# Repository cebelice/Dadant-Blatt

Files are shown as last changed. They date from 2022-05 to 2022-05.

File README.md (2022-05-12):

Dadant-Blatt panj
=================
Projekt vključuje detajlne risbe za izdelavo čebeljega nakladnega panja tipa Dadant-Blat.

Panj vključuje visoko podnico s smukalnikom cvetnega prahu oz. testno ploščo za varojo. Zasnova in dimenzije so plod raziskav slovenskih čebelarjev.

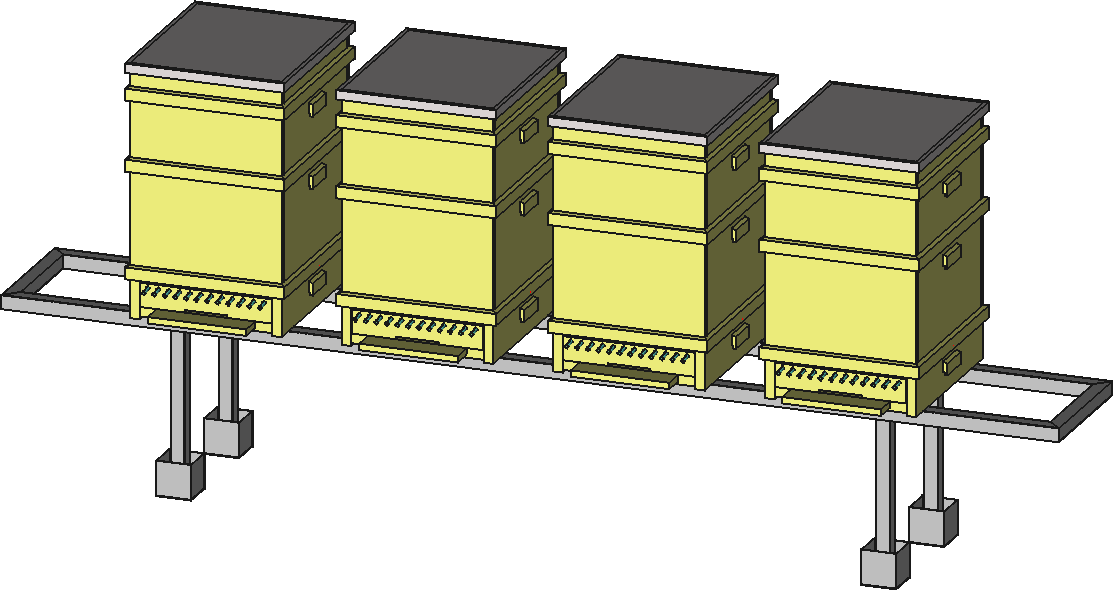
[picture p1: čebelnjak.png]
Čebelnjak z Dadant-Blat panji


Vsebina projekta
----------------
Projekt vsebuje 3-D model in sestavne ter delavniške risbe potrebne za izdelavo panja. Panj je možno izdelati s hobi orodjem.

Material je po večini lepljen smrekov ali jelov les, ki se dobi v obliki skobljanih plošlč različnih širin in debelin. V projektu se večinoma uporabljajo plošče debeline 18 in 27 mm, kot na [tej povezavi](https://trgovina.slovenijales.si/lesni-materiali/lepljene-plosce/lepljene-plosce-smreka/lepljena-plosca-smrekajelka-27-mm-300-x-2500-mm-kvaliteta).

3-D modeli sestavnih delov panja in samega panja imajo končnico ``.FCStd`` in se odpirajo s programom FreeCAD, ki je prost za uporabo. V posameznem modelu je npr. možno enostavno spremeniti v spremenljivkah debelino stene okvirja (npr. s 27 na 25 mm) in vse risbe letvic se avtomatsko ustrezno popravijo. Kratka navodila za uporabo v programu FreeCAD so [tukaj](FreeCAD/README.md).

Vsebina projekta so tudi ``.pdf`` datoteke z risbami, ki se lahko natisnejo. Generirane so iz posamezih ``.FCStd`` datotek. Zraven je tudi nekaj slik ``.png`` in pa datoteka LICENSE, ki [omogoča prosto uporabo](https://sl.wikipedia.org/wiki/Licenca_Apache).

Uporaba projekta in sodelovanje
-------------------------------
Projekt je prosto dostopen na https://github.com/cebelice/Dadant-Blatt. Cel projekt se lahko prenese na svoj računalnik (gumb Code).

Komentarji, težave in predlogi ali razprava lahko poteka v zavihku "Issues" (potrebna je brezplačna registracija).

Bolj vešči uporabniki lahko naredijo "Fork" projekta na svoj račun na Githubu, ga dopolnjujejo po svoje in dopolnitve po želji pošljejo nazaj kot "Pull request". "git" je orodje za nadzor različic, ki hrani celo zgodovino projekta in običajno prikazuje samo datoteke iz najnovejše verzije. Precej ga uporabljajo programerji ampak primeren je tudi za projekt, kot je tale.

Visoka podnica in smukalnik cvetnega prahu
------------------------------------------
Avtor visoke podnice in smukalnika je Brane Borštnik in daje načrte v prosto uporabo.

Viskoka podnica se lahko uporablja na dva načina:

### S smukalnikom cvetnega prahu
V podnico se od zadaj vstavi "smukalnik" in "smukalnik_mreza". Z mreže se dnevno odstranjuje cvetni prah in se ga takoj zamrzne.

### Z mrežo in testno ploščo
Namesto smukalnika se vstavi "podnica_mreza" in pod njo "testna_plosca" za varojo, ki se jo na tanko namaže z litijevo mastjo. Priporoča se izdelavo testne plošče iz materiala [Forex](http://www.sign-supply.si/forex-plosce-unipan/forex-plosce.html), 3mm.

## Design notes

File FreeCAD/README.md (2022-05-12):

Uporaba programa FreeCAD
========================

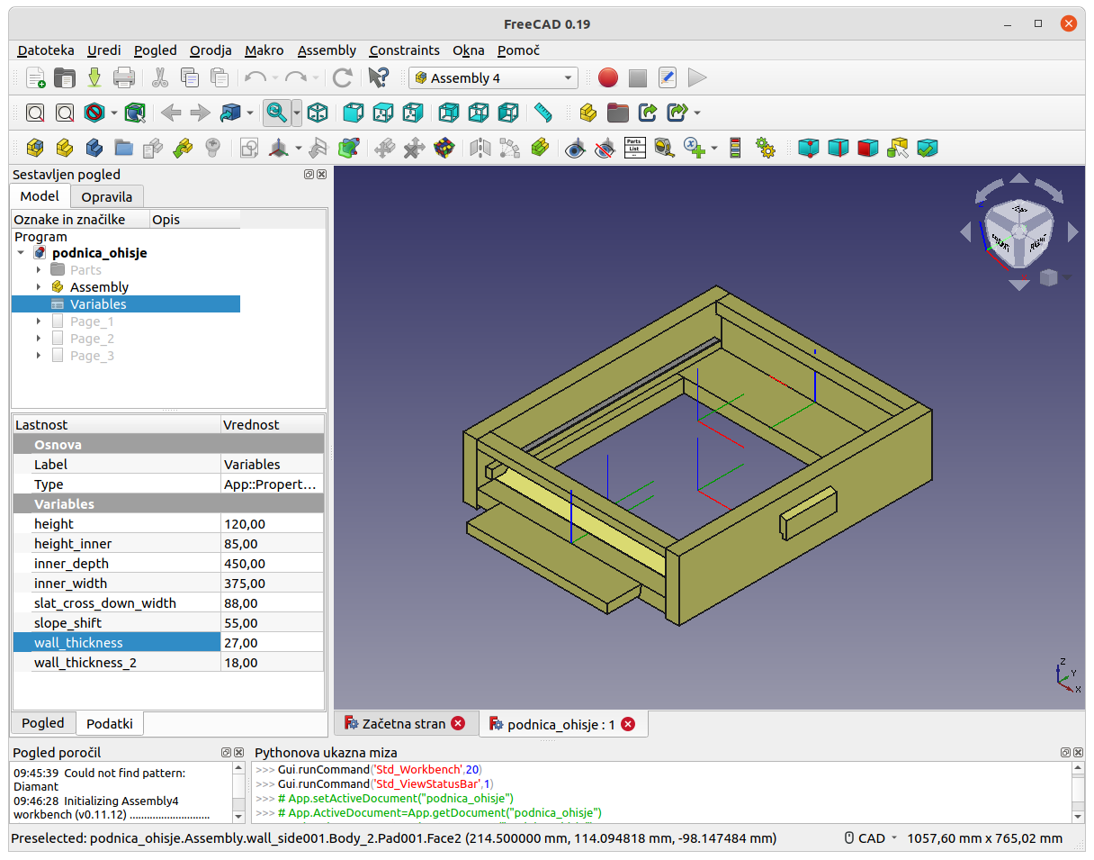
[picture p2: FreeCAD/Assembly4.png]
Assembly4

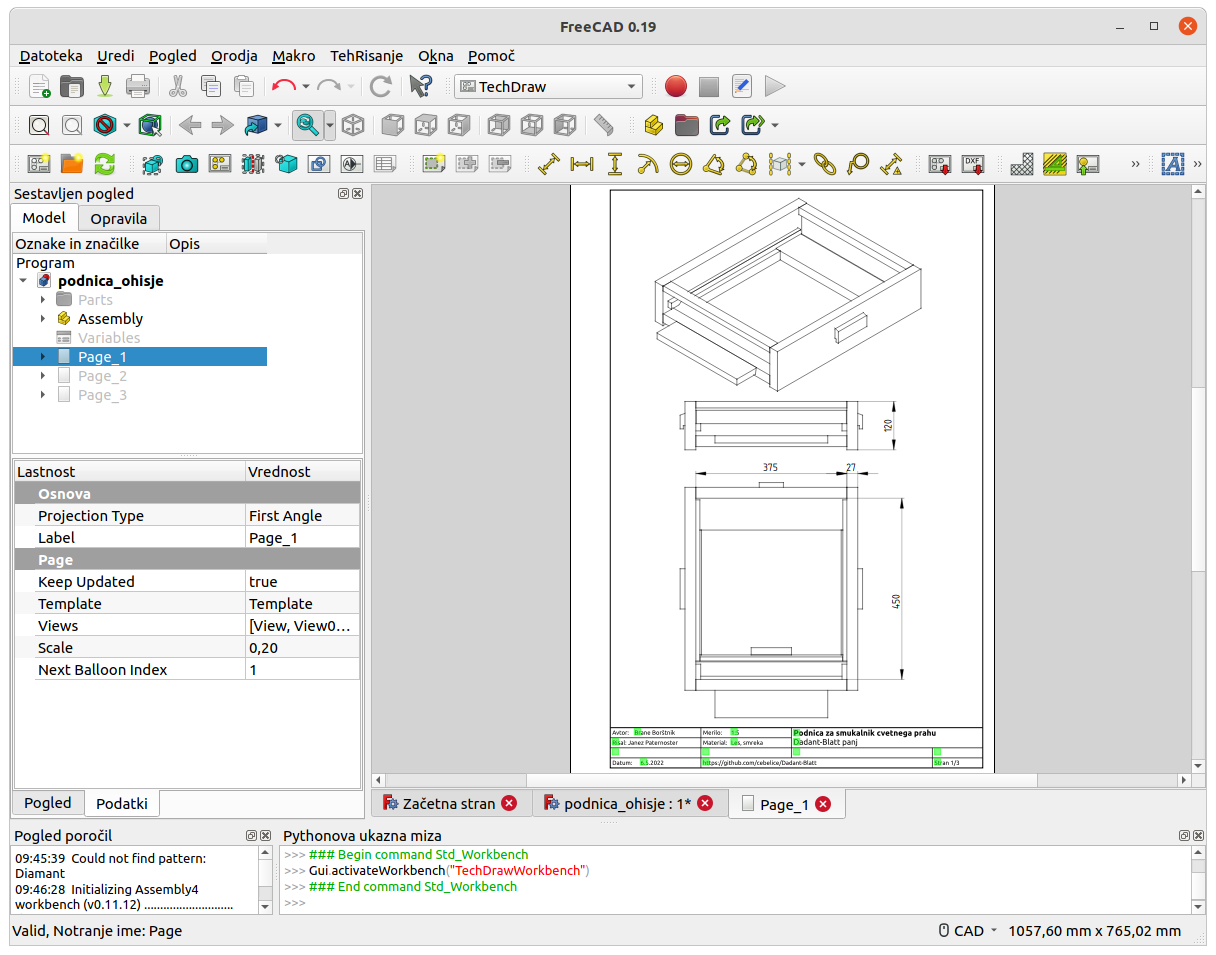
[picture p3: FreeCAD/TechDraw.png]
TechDraw


FreeCAD je prost program za tehnično 3-D modeliranje. Ni tako izpopolnjen kot podobni komercialni programi je dovolj dober za ta projekt.

Namestitev
----------
1. Namesti https://www.freecad.org/ V času tega pisanja je bila nameščena zadnja verzija, to je 0.19.
2. po nameščenem FreeCADu, znotraj programa: meni "Orodja" -> "Upravljalnik dodatkov" -> namesti modul "Assembly4"

Primeri uporabe programa
------------------------
- V programu odpreš datoteko "podnica_ohisje.FCStd".
- Desno v oknu je viden 3-D model ali 2-D risba. Premika se s pritiskom na srednjo tipko miške in vlečenjem. Vrti se s pritiskom desne tipke miške in hkratinim držanje tipke "shift" na tipkovnici.
- Okno levo zgoraj vsebuje drevesno strukturo elementov v datoteki "podnica_ohisje.FCStd":
  - Mapa "Parts" vsebuje posamezne sestavne dele modela "podnica_ohisje.FCStd".
  - Mapa "Assembly" vsebuje zgradbo celotnega sestava. Z izbiro posameznega dela v tej mapi ga lahko s tipko "preslednica" preklopimo njegovo vidnost. Isto velja za sestavne dele v mapi "Parts".
  - Predmet "Variables" vsebuje spremenljivke za dimenzije, ki se uporabljajo pri tem modelu.
    - Ob kliku na "Variables" se v spodnjem oknu pojavi seznam spremenljivk.
    - Za primer spremeni vrednost "wall_thickness" s 27 na 25 in debeline lesenih plošč v modelu se spremenijo.
    - Sprememba se odraža tudi v kotah na risbah.
  - "Page_1", "Page_2", "Page_3" (dvojni klik) vsebujejo tehnične risbe.

Model je seveda možno tudi popolnoma spremeniti. Za več informacij o uporabi programa FreeCAD glej:
- https://wiki.freecad.org/Getting_started
- https://wiki.freecad.org/Assembly4_Workbench
  - [Tutorial 1 for a quick assembly from scratch](https://github.com/Zolko-123/FreeCAD_Examples/blob/master/Asm4_Tutorial1/README.md)
  - [Tutorial 2 for a cinematic assembly in one file, using a master sketch](https://github.com/Zolko-123/FreeCAD_Examples/blob/master/Asm4_Tutorial2/README.md)
- https://wiki.freecad.org/TechDraw_Workbench
  - https://wiki.freecad.org/Basic_TechDraw_Tutorial

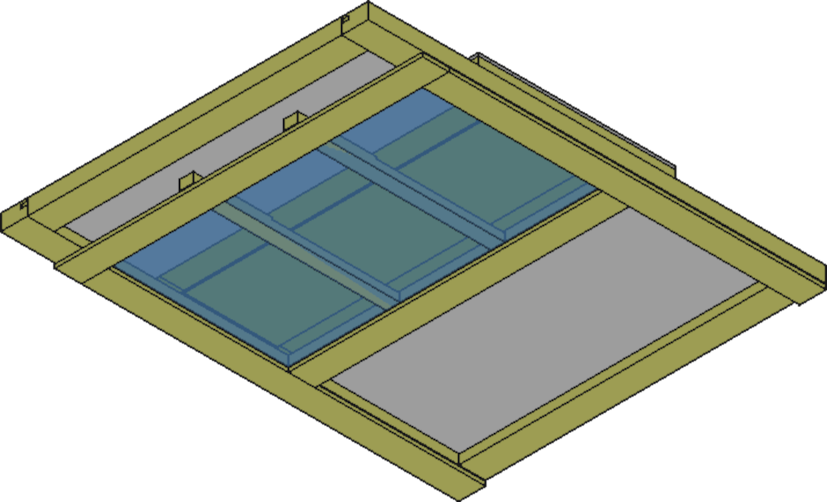
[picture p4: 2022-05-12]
smukalnik_2.png

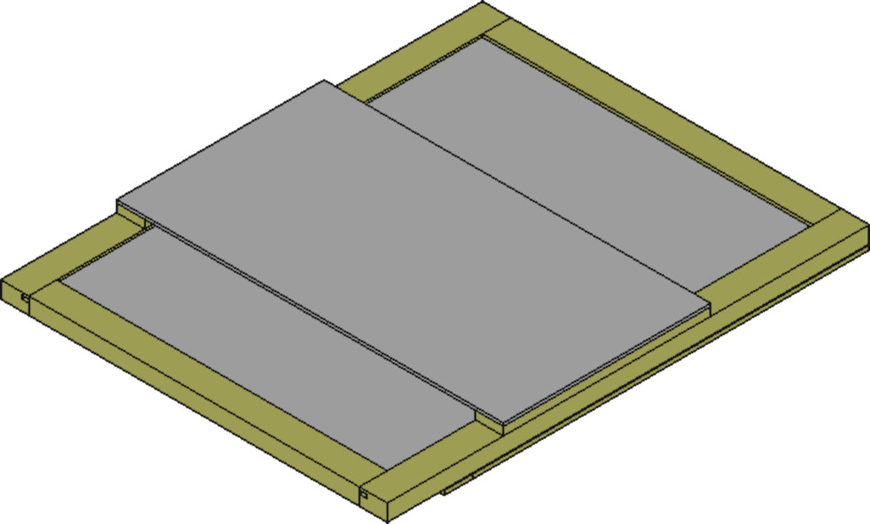
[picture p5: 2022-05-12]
smukalnik_1.png

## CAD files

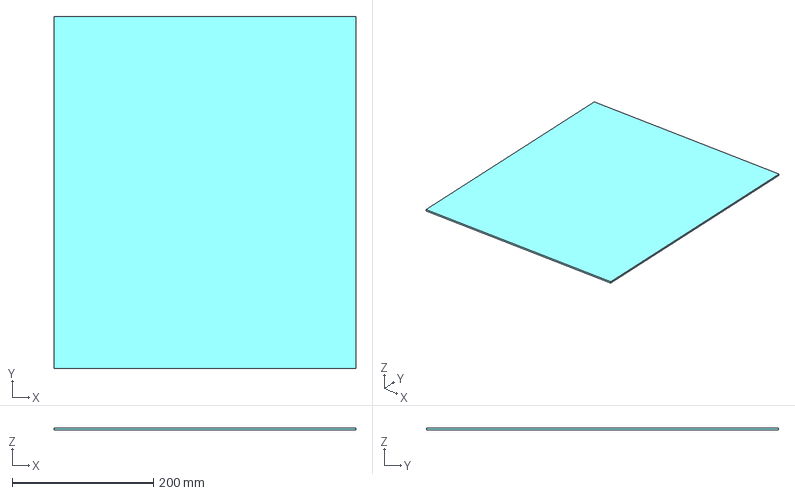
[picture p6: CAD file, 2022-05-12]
panj.FCStd
428.0 x 499.0 x 3.00 mm

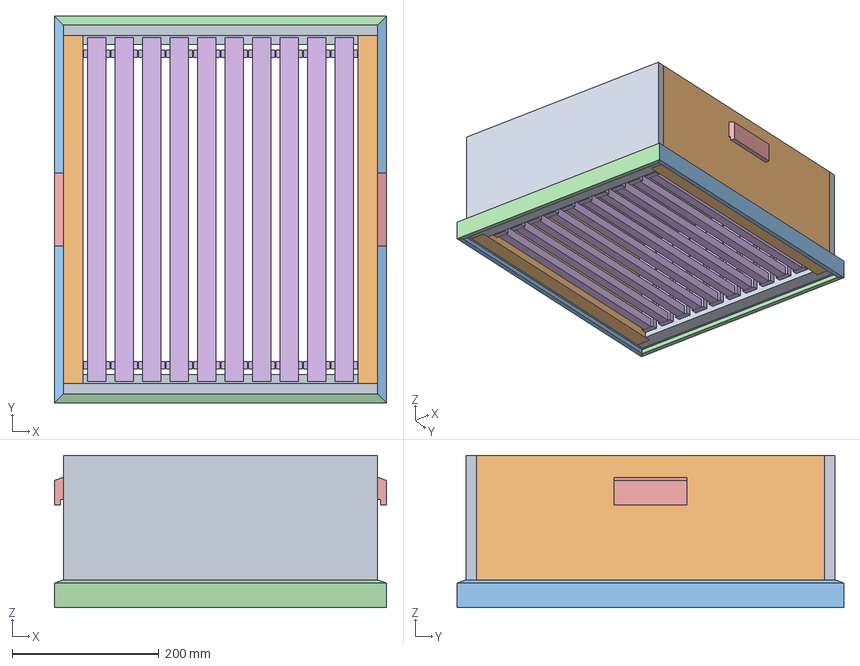
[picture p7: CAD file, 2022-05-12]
naklada_nizka.FCStd
453.0 x 528.0 x 208.0 mm

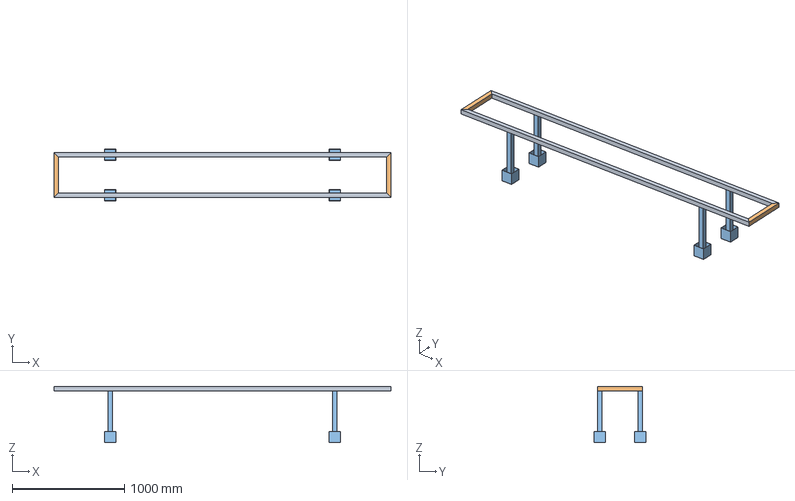
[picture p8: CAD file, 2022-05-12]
podstavek.FCStd
3000.0 x 460.0 x 500.0 mm

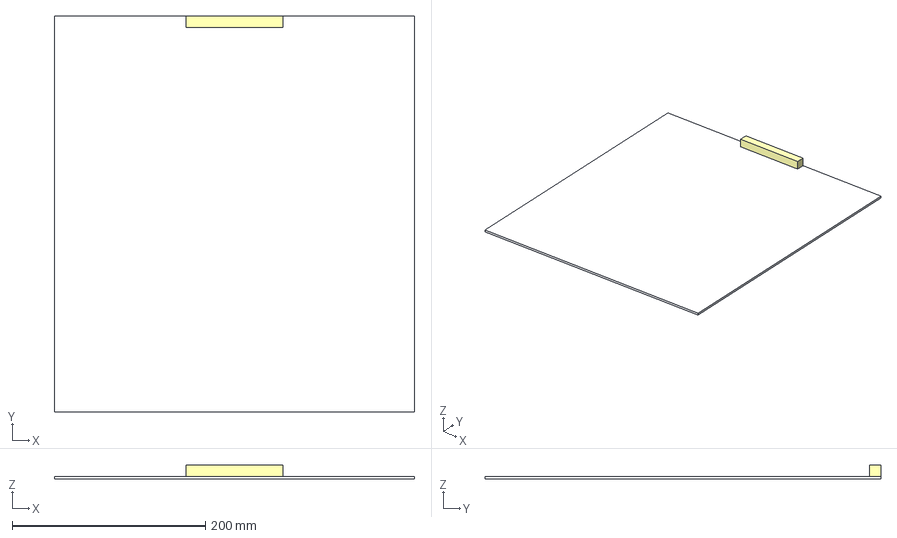
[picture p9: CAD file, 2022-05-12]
testna_plosca.FCStd
373.0 x 410.0 x 15.0 mm

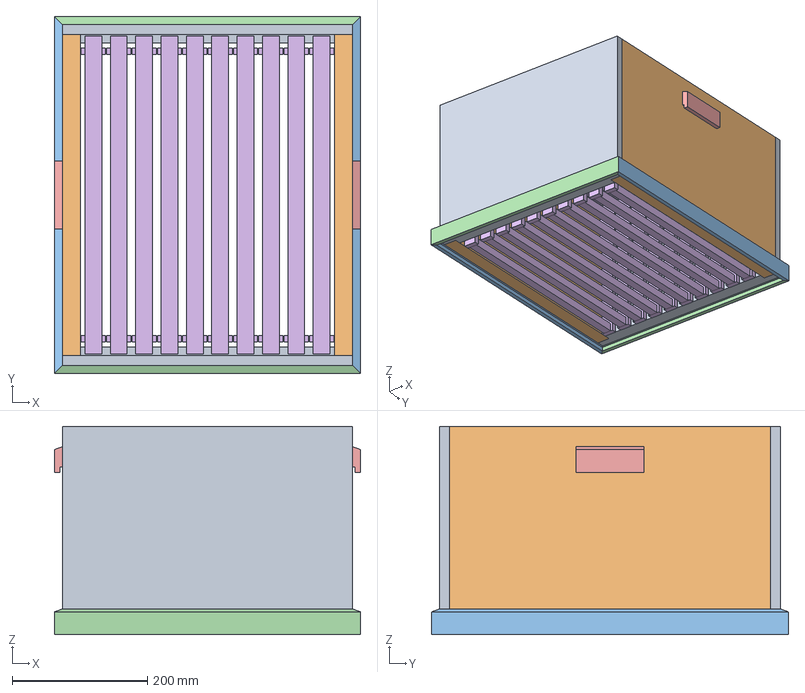
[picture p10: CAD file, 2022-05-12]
naklada.FCStd
453.0 x 528.0 x 308.0 mm

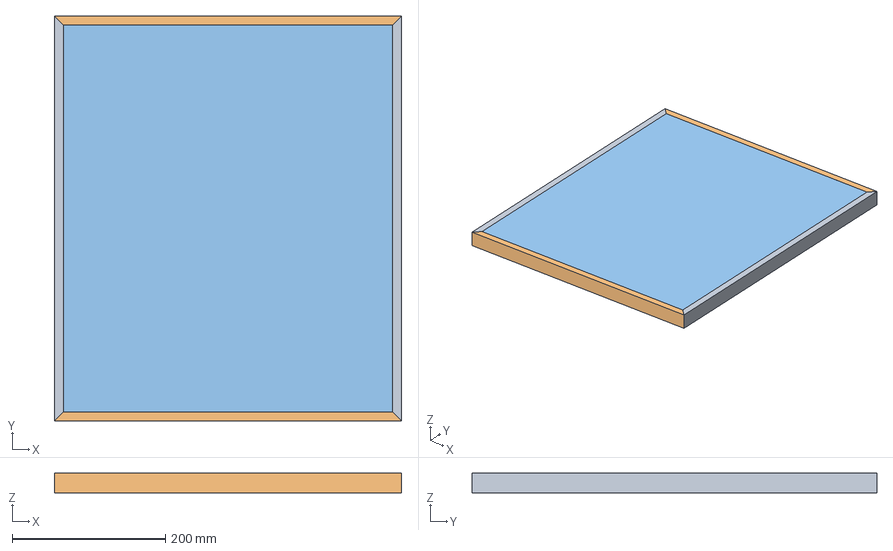
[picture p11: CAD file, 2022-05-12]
streha.FCStd
453.0 x 528.0 x 26.0 mm

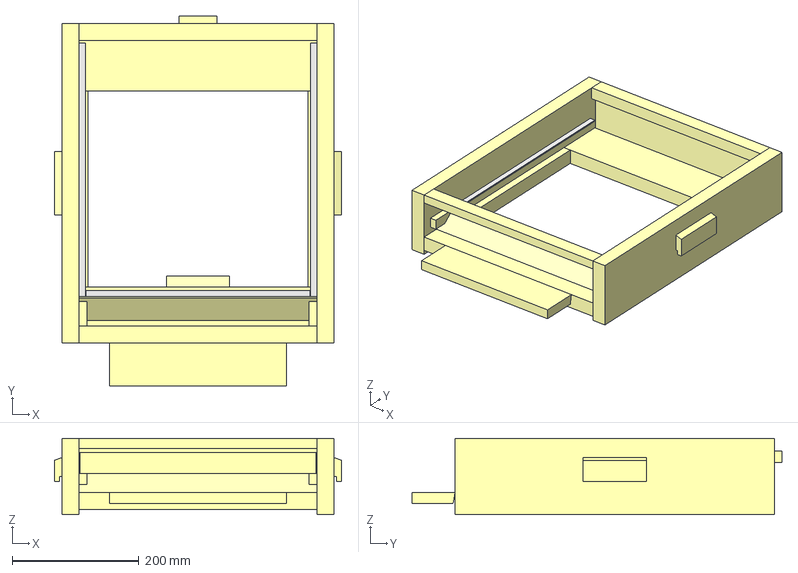
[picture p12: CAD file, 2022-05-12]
podnica_ohisje.FCStd
453.0 x 584.0 x 120.0 mm

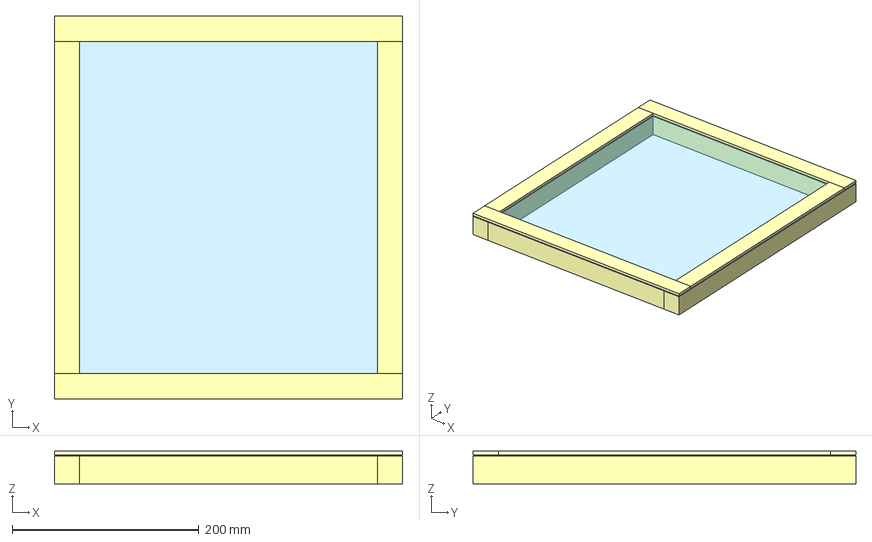
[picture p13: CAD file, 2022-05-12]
podnica_mreza.FCStd
373.0 x 410.0 x 35.0 mm

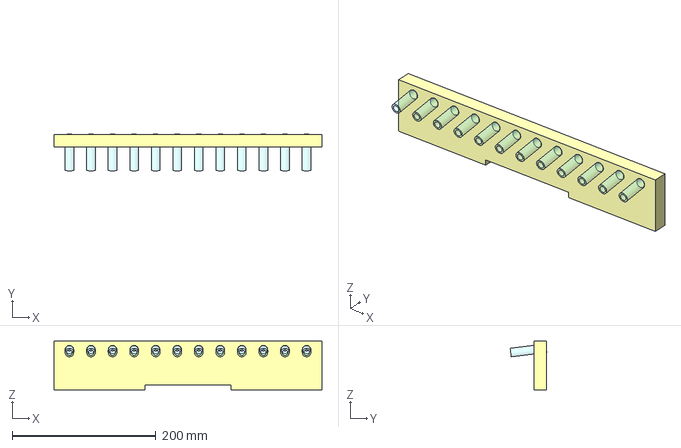
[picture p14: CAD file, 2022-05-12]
podnica_pokrovcek.FCStd
373.0 x 51.1 x 68.0 mm

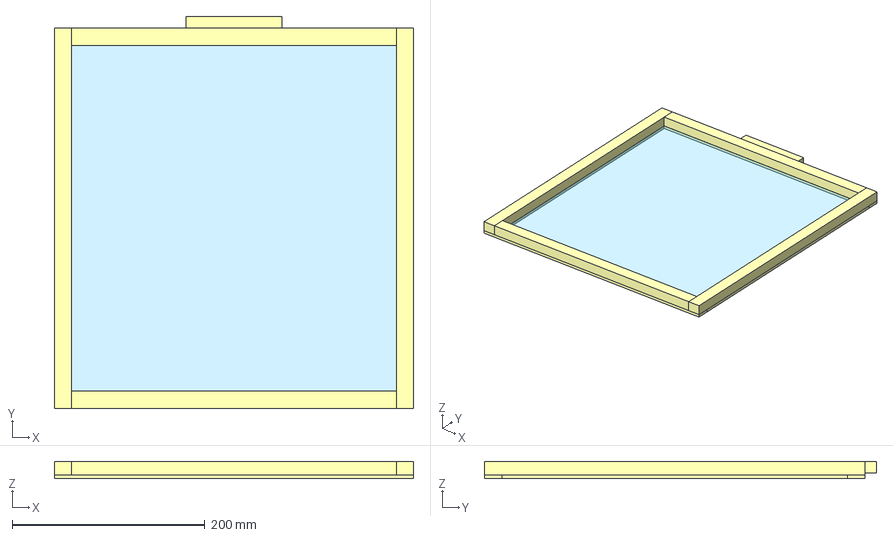
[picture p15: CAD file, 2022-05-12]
smukalnik_mreza.FCStd
373.0 x 407.0 x 18.0 mm

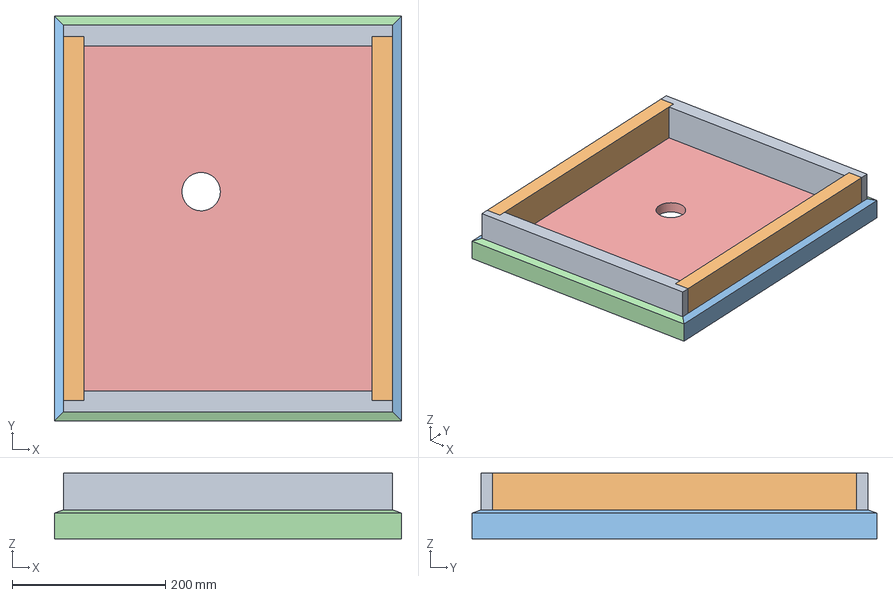
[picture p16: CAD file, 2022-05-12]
pokrov.FCStd
453.0 x 528.0 x 86.0 mm

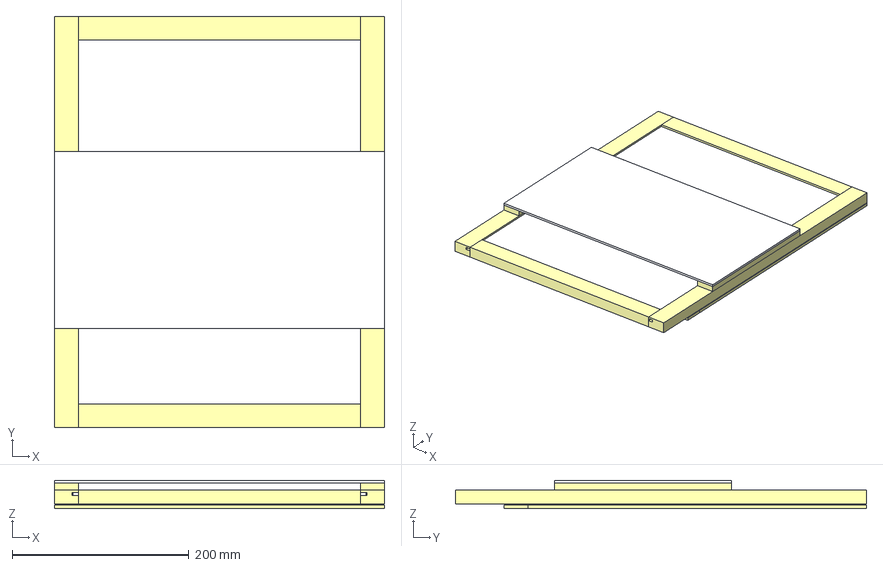
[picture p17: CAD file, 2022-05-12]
smukalnik.FCStd
373.0 x 465.0 x 32.0 mm

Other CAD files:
cebelnjak.FCStd

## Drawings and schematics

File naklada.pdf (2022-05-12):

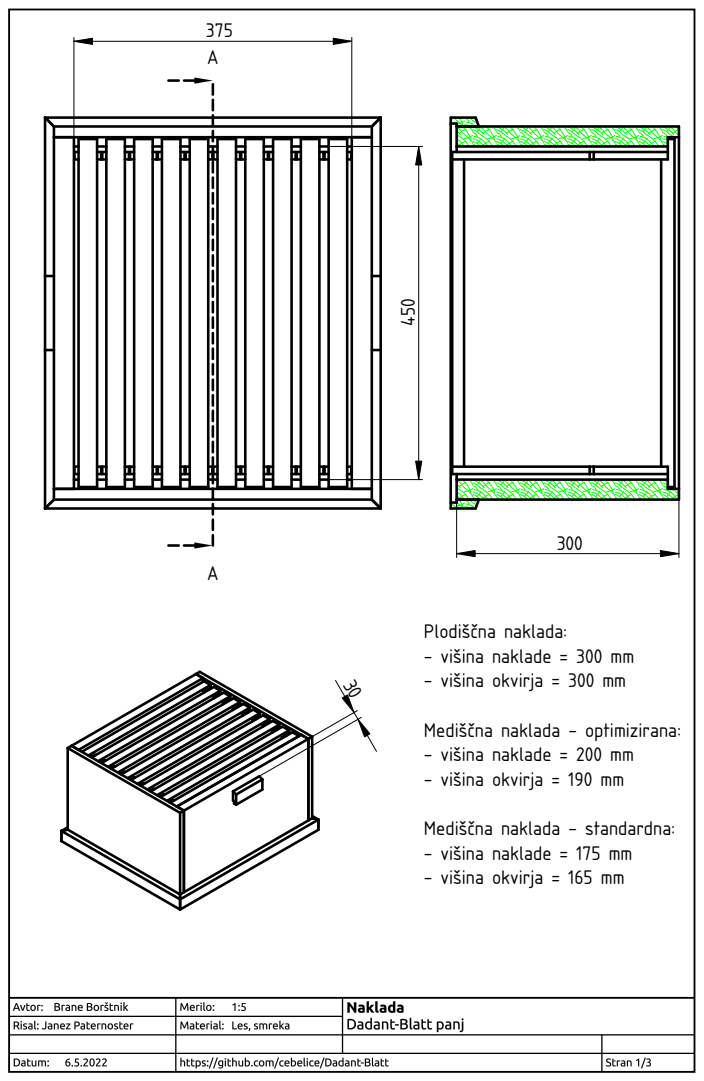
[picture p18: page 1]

Plodiščna naklada:
- višina naklade = 300 mm
- višina okvirja = 300 mm
Mediščna naklada - optimizirana:
- višina naklade = 200 mm
- višina okvirja = 190 mm
Mediščna naklada - standardna:
- višina naklade = 175 mm
- višina okvirja = 165 mm

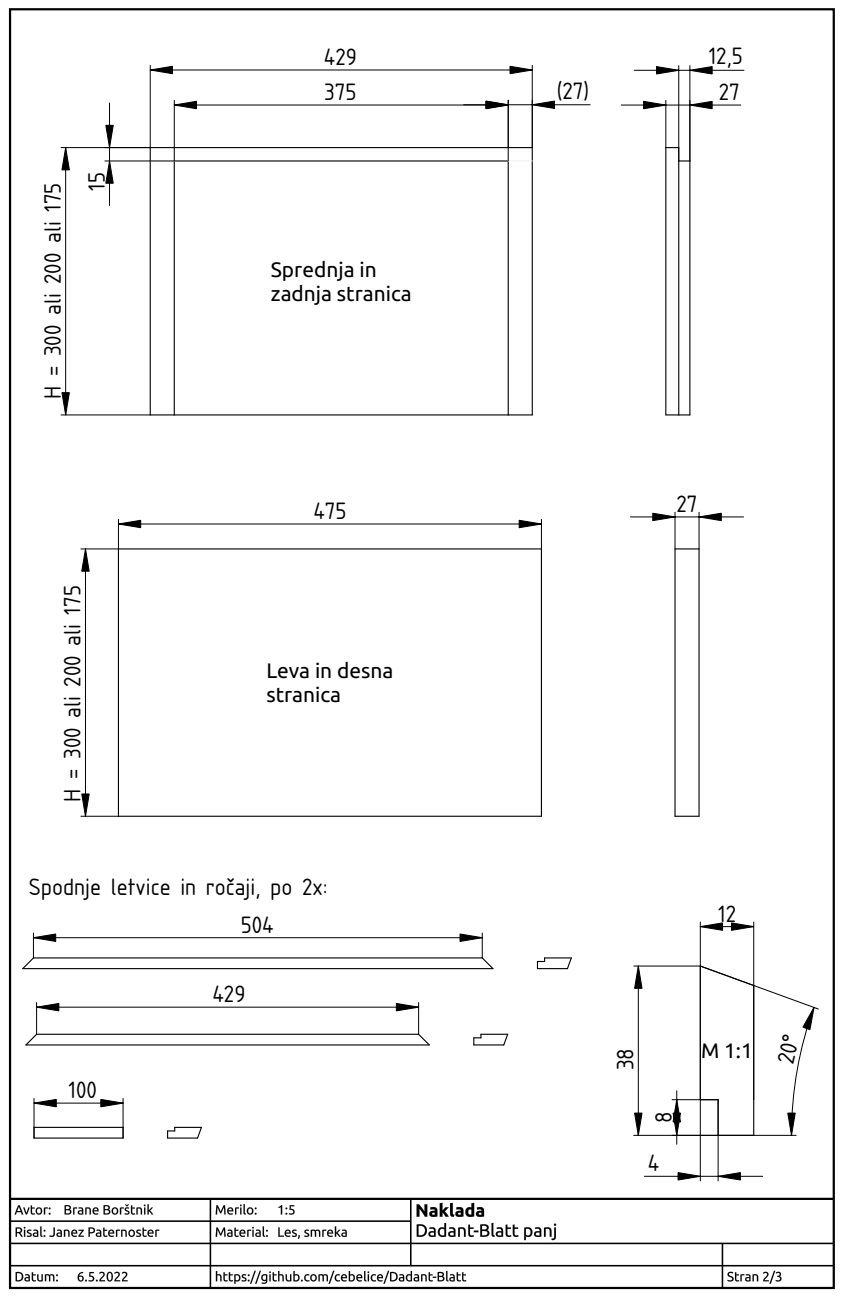
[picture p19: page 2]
ali 2; ali 17; Sprednja in zadnja stranica

Leva in desna
stranica

Spodnje letvice in ročaji, po 2x:

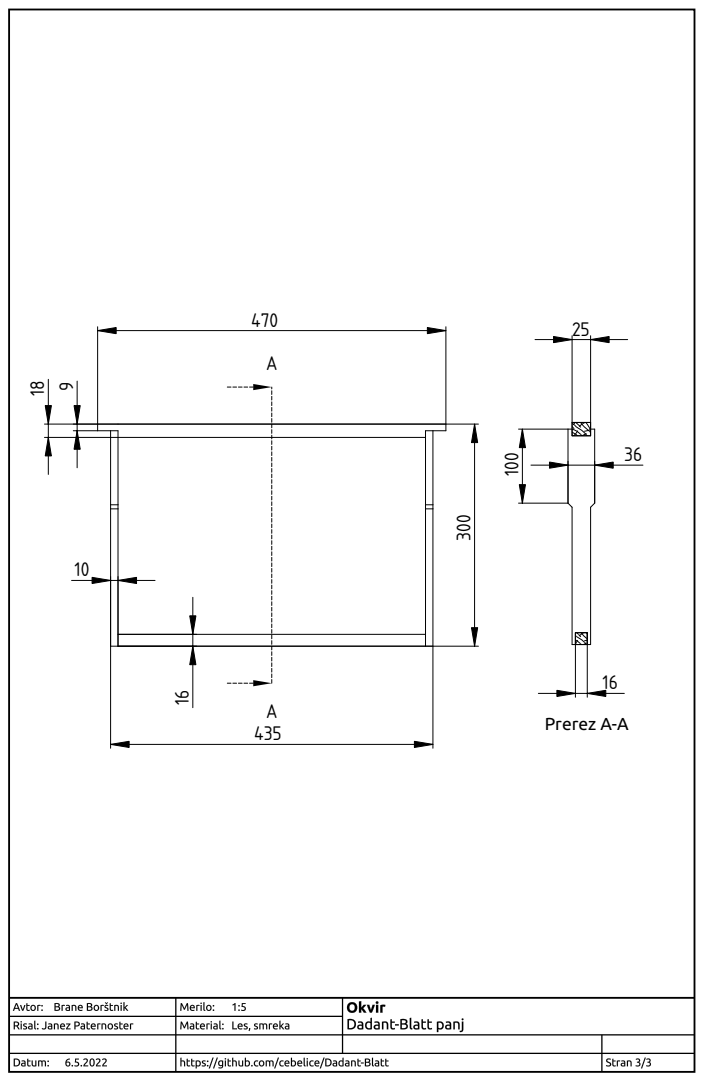
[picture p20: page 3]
Prere

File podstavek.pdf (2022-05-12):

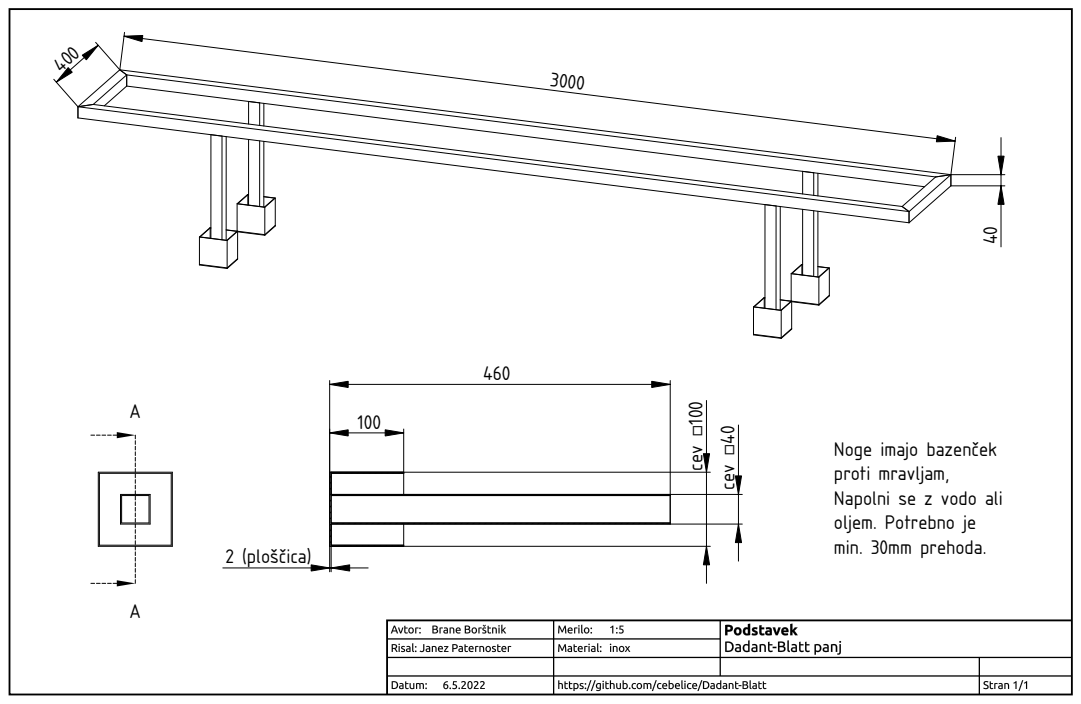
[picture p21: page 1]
cev ▫40; cev ▫100 100 460; 2 (plo; ščica); ajo; nče; vlja; m, Napolni se z v o

proti mra
ali oljem. Potrebno je min. 30mm prehoda.

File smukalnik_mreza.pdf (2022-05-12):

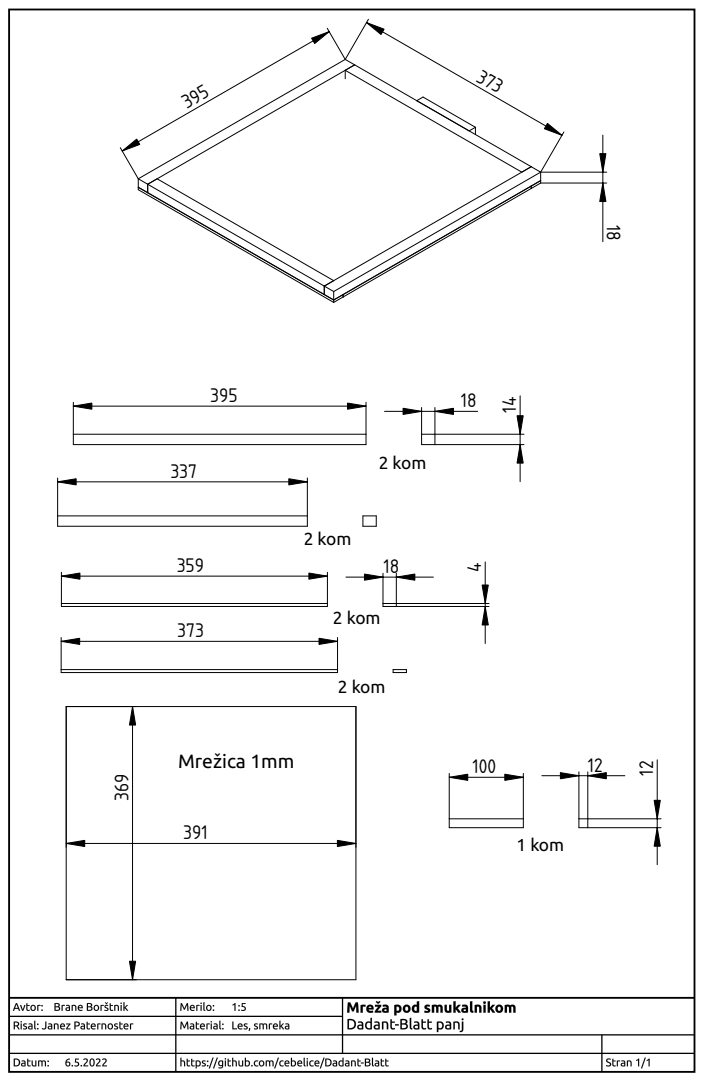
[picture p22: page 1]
2 kom; Mrežica 1mm; 1 kom

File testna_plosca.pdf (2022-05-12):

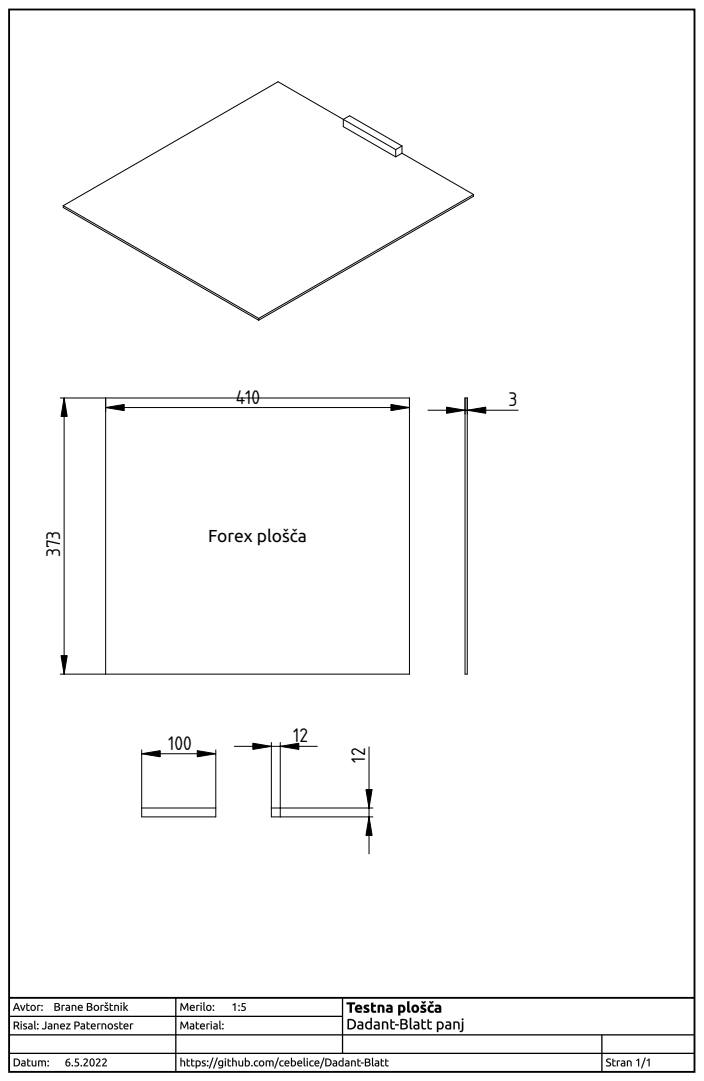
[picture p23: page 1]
Forex plošča

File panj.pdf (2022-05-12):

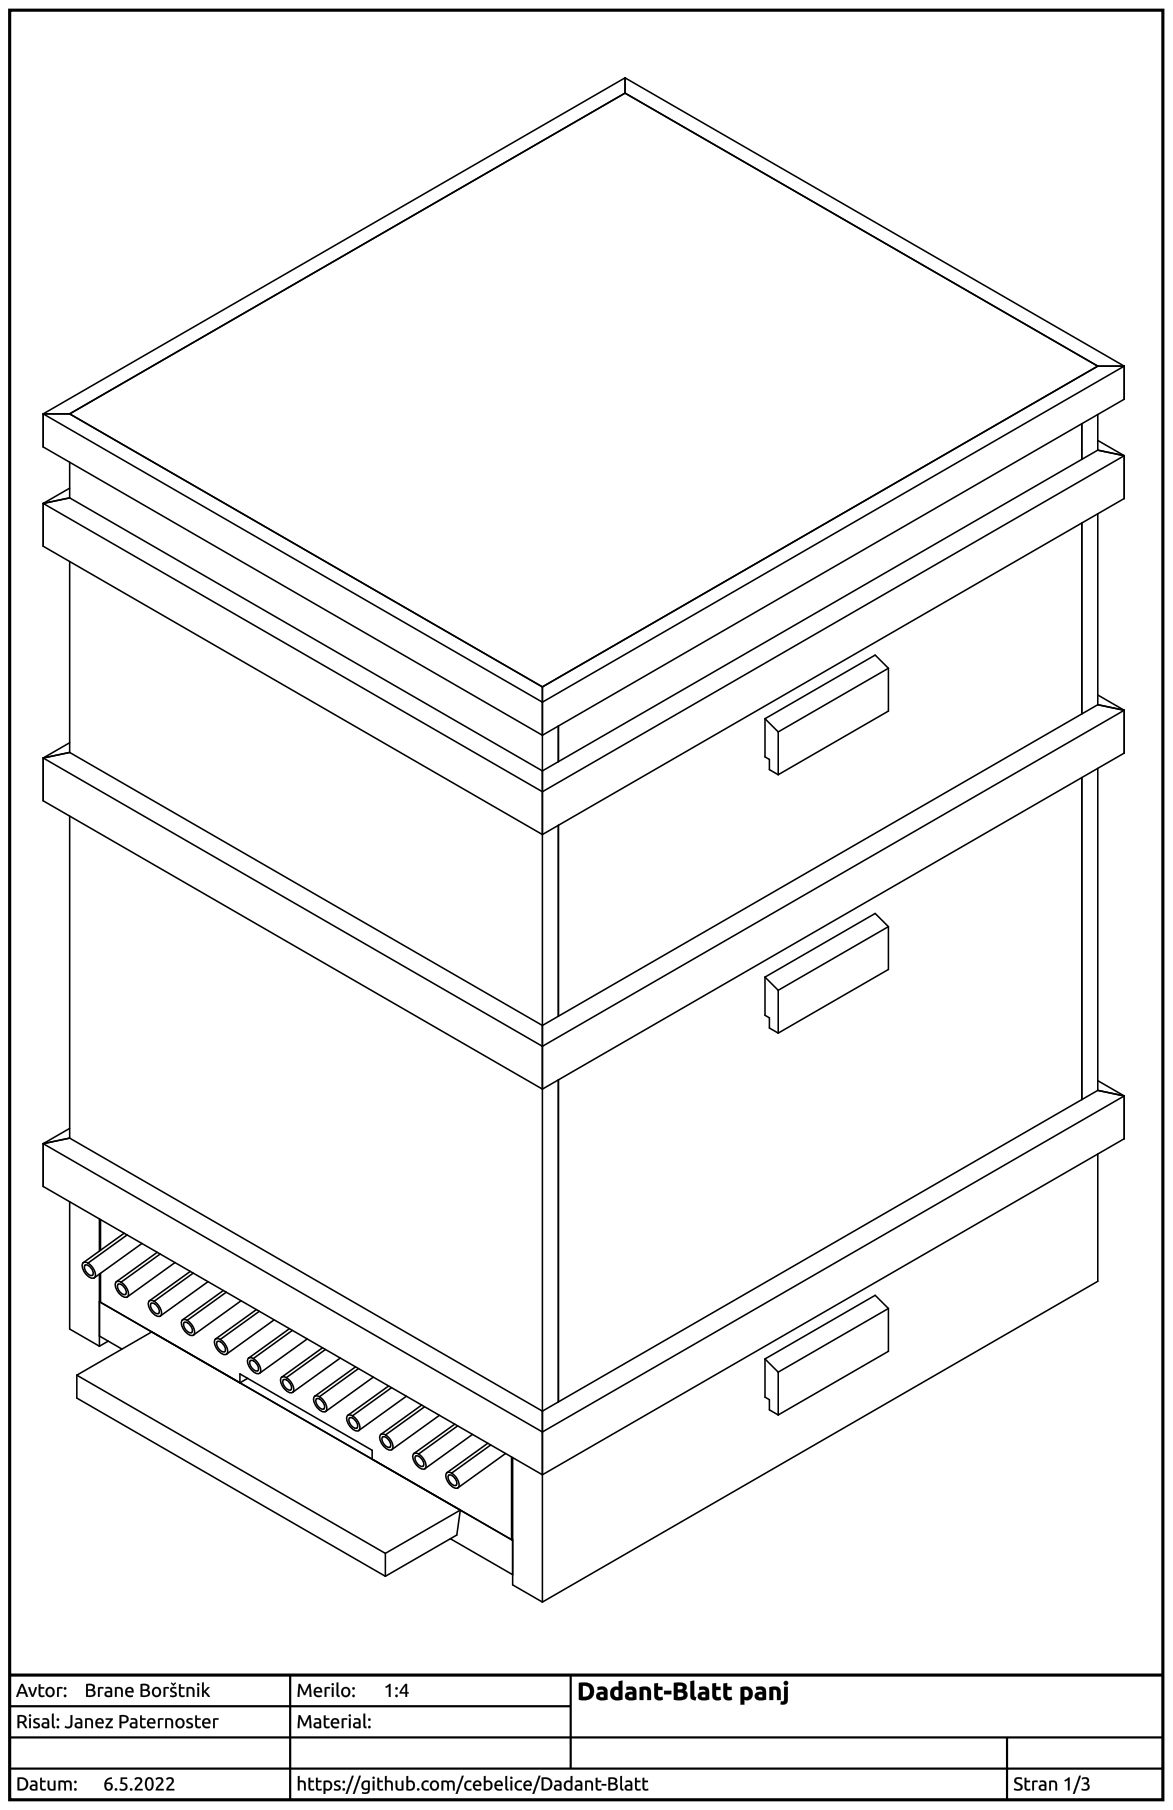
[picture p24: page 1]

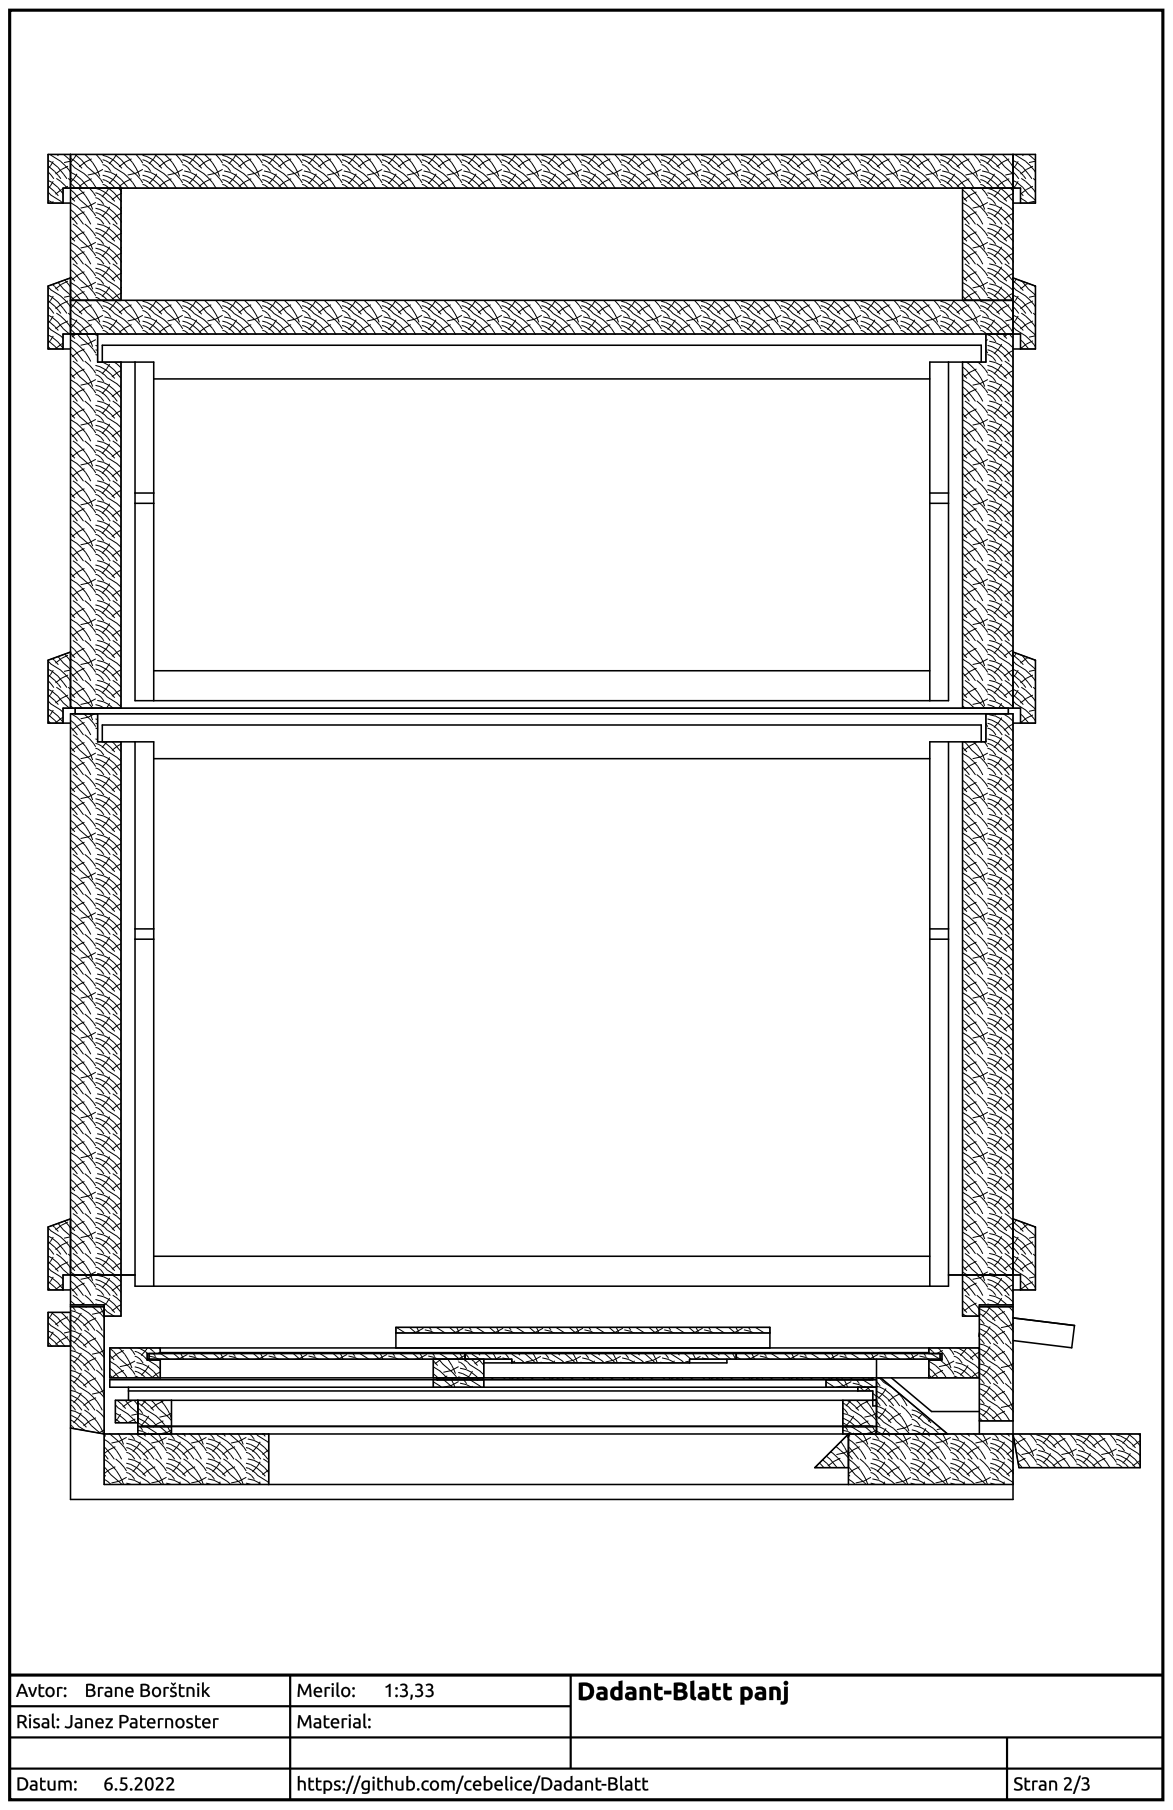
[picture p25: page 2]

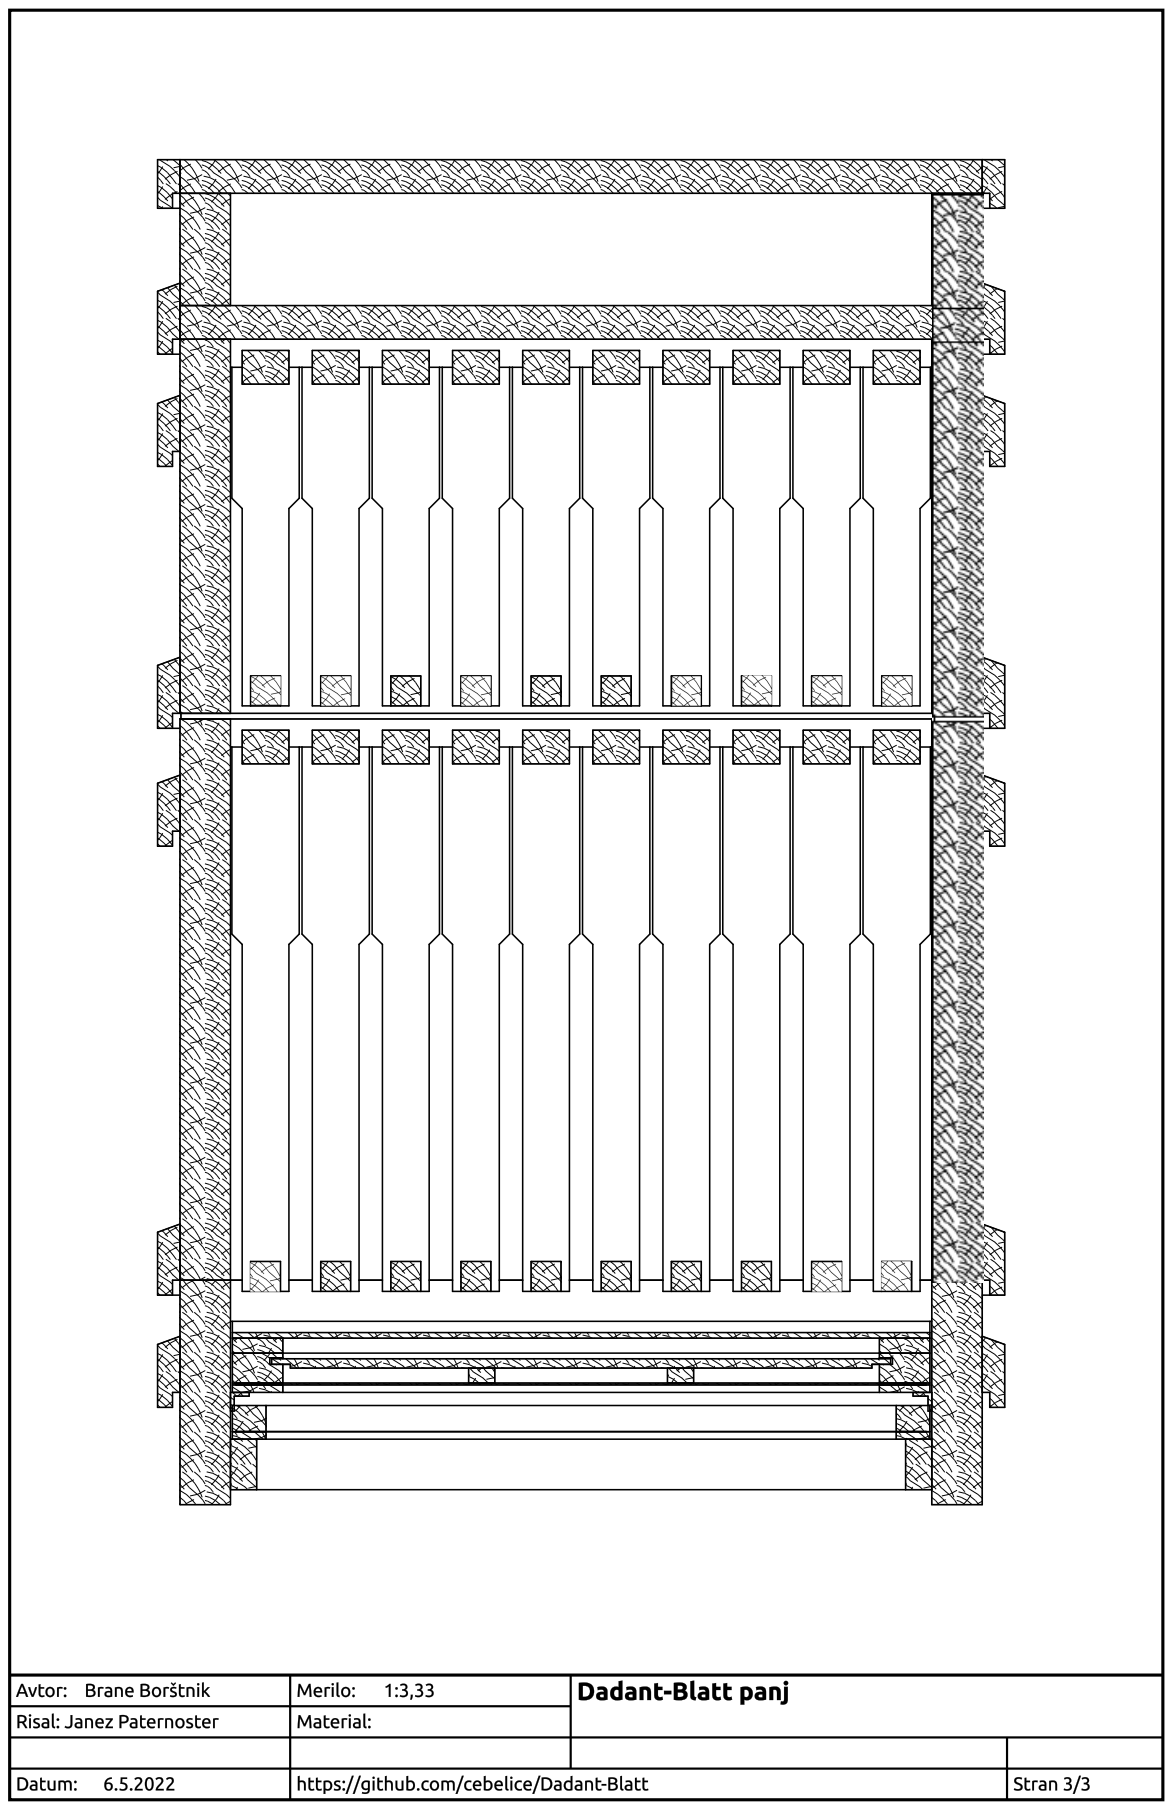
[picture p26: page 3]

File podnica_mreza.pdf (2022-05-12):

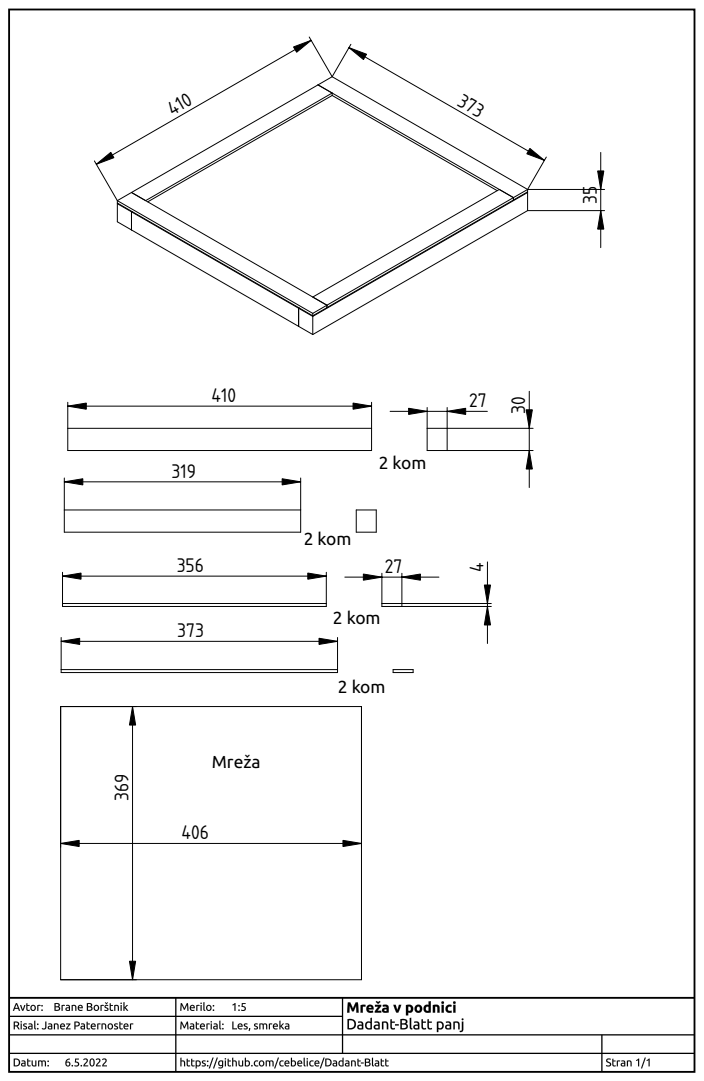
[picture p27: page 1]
2 kom; Mreža

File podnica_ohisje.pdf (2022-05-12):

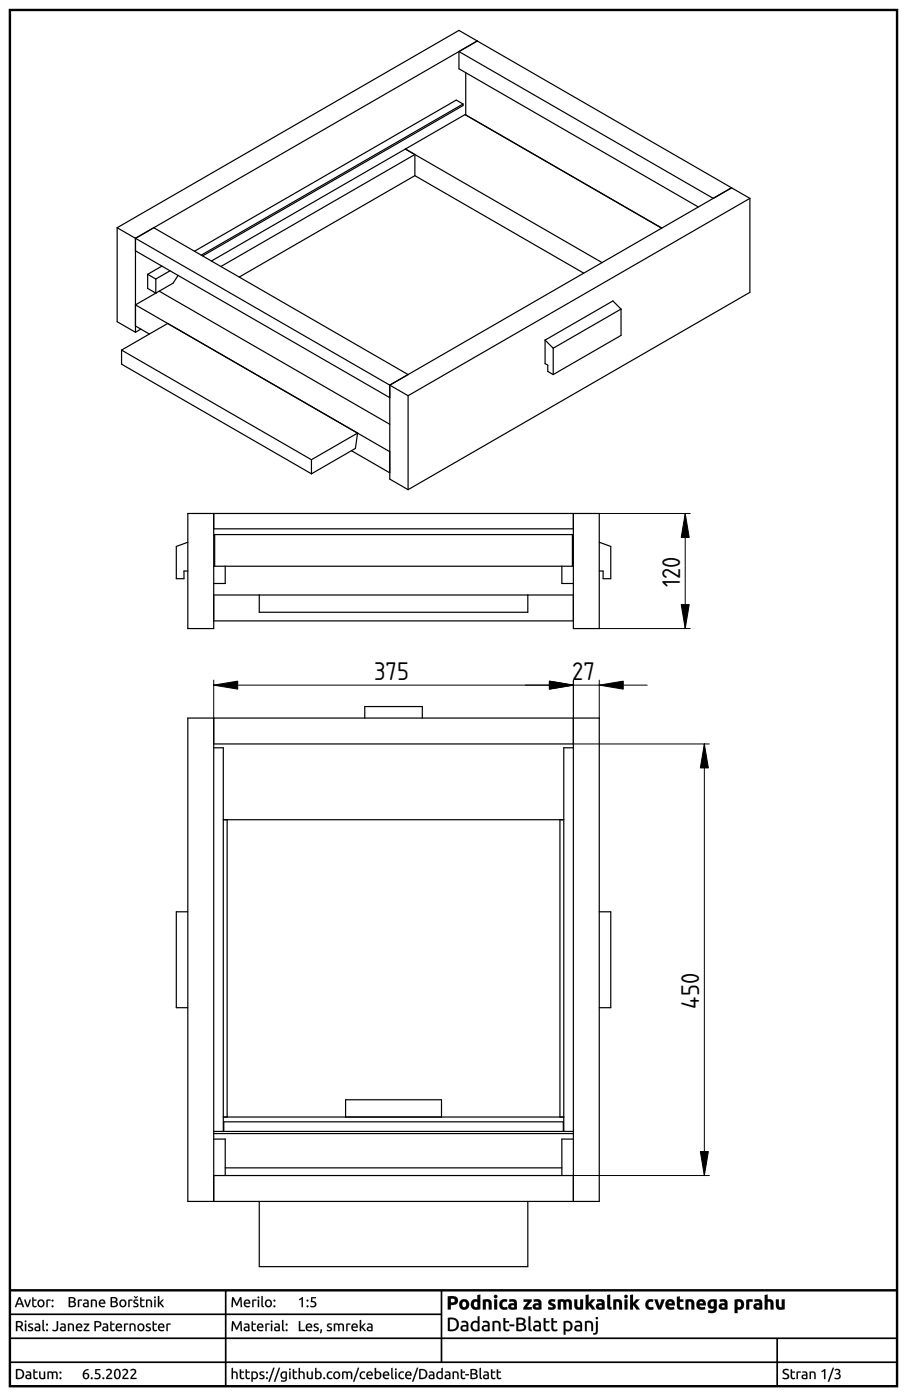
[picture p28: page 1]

27

73

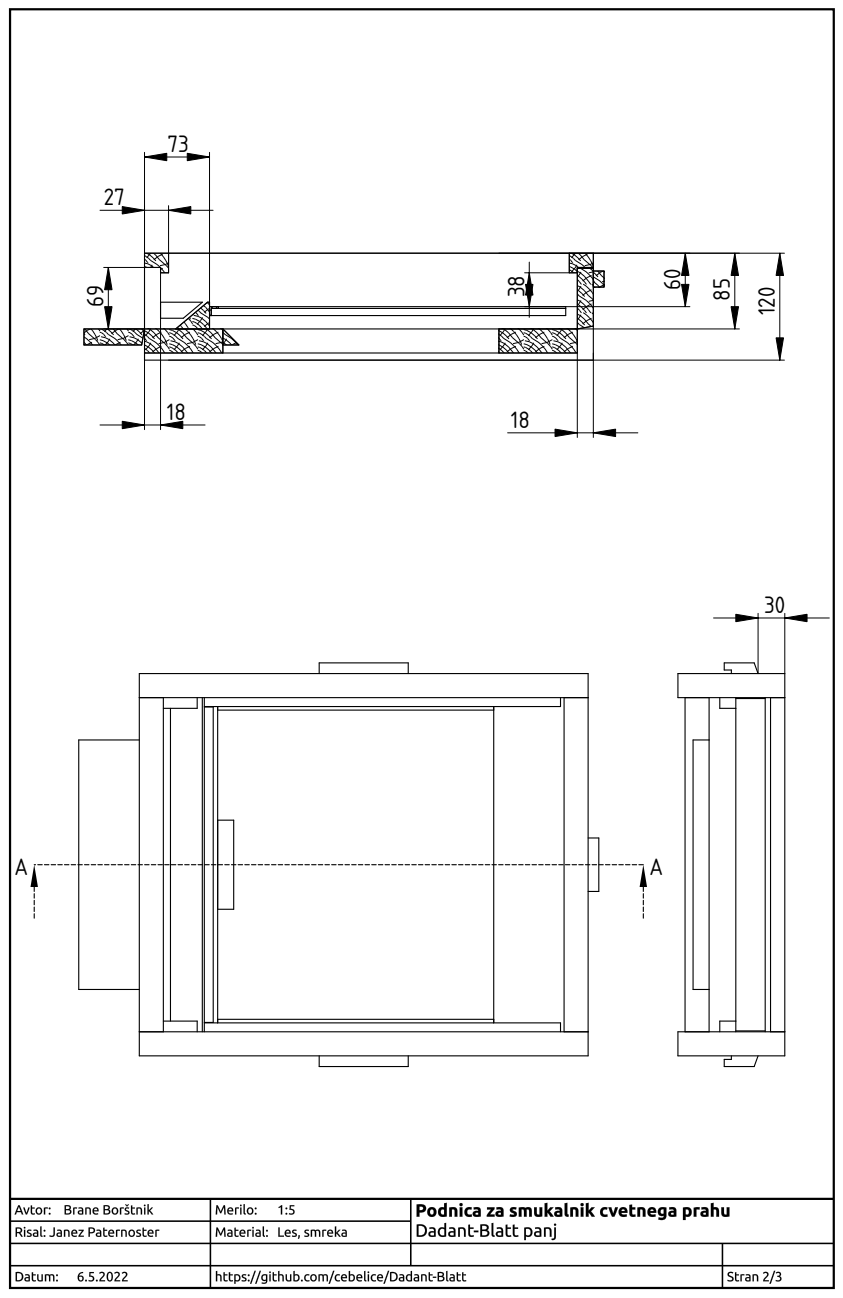
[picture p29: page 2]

504

120

2 kom; 1 kom; 2 kom 354 Al kotnik 10x10

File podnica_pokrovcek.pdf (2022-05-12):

373
30

1 kom; Cevke, 12 kom

Pokrovček za smukalnik. V luknje se vstavijo cevke, ki naj bodo obrnjene rahlo navzdol 1 kom

Navaden pokrovček na podnici

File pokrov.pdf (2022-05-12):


2 kom

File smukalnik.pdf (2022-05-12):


112 200


465

27

2 kom; 1 kom; Forex plošča 1 kom; Mrežica; Smukalna mrežica

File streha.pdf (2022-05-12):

2 kom

Zgoraj prekrito s pločevino.

(debelina stene panja = 27)
